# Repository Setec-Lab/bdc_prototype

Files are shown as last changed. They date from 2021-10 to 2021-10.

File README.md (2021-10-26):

Bi-directional converter based EPS prototype for small satellites
============

### Most recent version of this repository can be found in: ###

* [GitHub](https://github.com/Setec-Lab/bdc_prototype)

### What is this repository for? ###

* This repository includes testing software, embeded related software, hardware schematics and drawings and in general everything that is needed to build a copy of the system known as **Bi-directional converter based EPS prototype for small satellites**. 

### How do I get set up? ###

* **UPDATE AS IT GROWS**

### Contribution guidelines ###

* If you want to propose a review or need to modify the code for any reason first fork this [repository](https://github.com/Setec-Lab/bdc_prototype) in your system and create a new branch for your changes. Once your changes are complete and fully tested make a pull request.
* If you just want to do local changes instead you can download a zip version of the repository and do all changes locally in your system. 

### Who do I talk to? ###

* [Juan J. Rojas](mailto:juan.rojas@itcr.ac.cr)

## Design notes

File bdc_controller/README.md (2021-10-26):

BDC Prototype -- README {#mainpage}
============

### Most recent version of this repository can be found in: ###

* [Bitbucket](https://bitbucket.org/juanjorojash/bdc_prototype/src/master)

### Documentation ###

* Full documentation in HTLM version can be found in **documentation/htlm/index.htlm**

### What is this repository for? ###

* This repository was created to be used in conjuction with the integrated system known as "BDC_Prototype.V1.1". It was created to control the PIC16F1786 installed for feedback control, and serial logging.
* Hardware version: BDC_Prototype.V1.1

### How do I get set up? ###

* Connect usign serial cable. 
* **Serial terminal** Start with the following settings BR:19200 kbps, Data: 8 bit, Parity: none, Stop bits: 1, Flow control: none. 
* **LabView logger program** A program for receiving, saving and plotting the test data is included in the repository, in the directory **logger/main.vi**. The following programs are needed in order to run this program in a PC that **does not** have LabView installed:
	* [LabVIEW Run-Time Engine 2016 - (64-bit)](http://www.ni.com/download/labview-run-time-engine-2016/6067/en/) 
	* [NI-VISA Run-Time Engine 16.0](http://www.ni.com/download/ni-visa-run-time-engine-16.0/6188/en/)
The program creates the directory **c:/BDC_logger_data** to store the data.

### Contribution guidelines ###

* If you want to propose a review or need to modify the code for any reason first clone this [repository](https://bitbucket.org/juanjorojash/bdc_prototype/src/master) in your PC and create a new branch for your changes. Once your changes are complete and fully tested ask the administrator permission to push this new branch into the source.
* If you just want to do local changes instead you can download a zip version of the repository and do all changes locally in your PC. 

### Who do I talk to? ###

* [Juan J. Rojas](mailto:juan.rojas@itcr.ac.cr)

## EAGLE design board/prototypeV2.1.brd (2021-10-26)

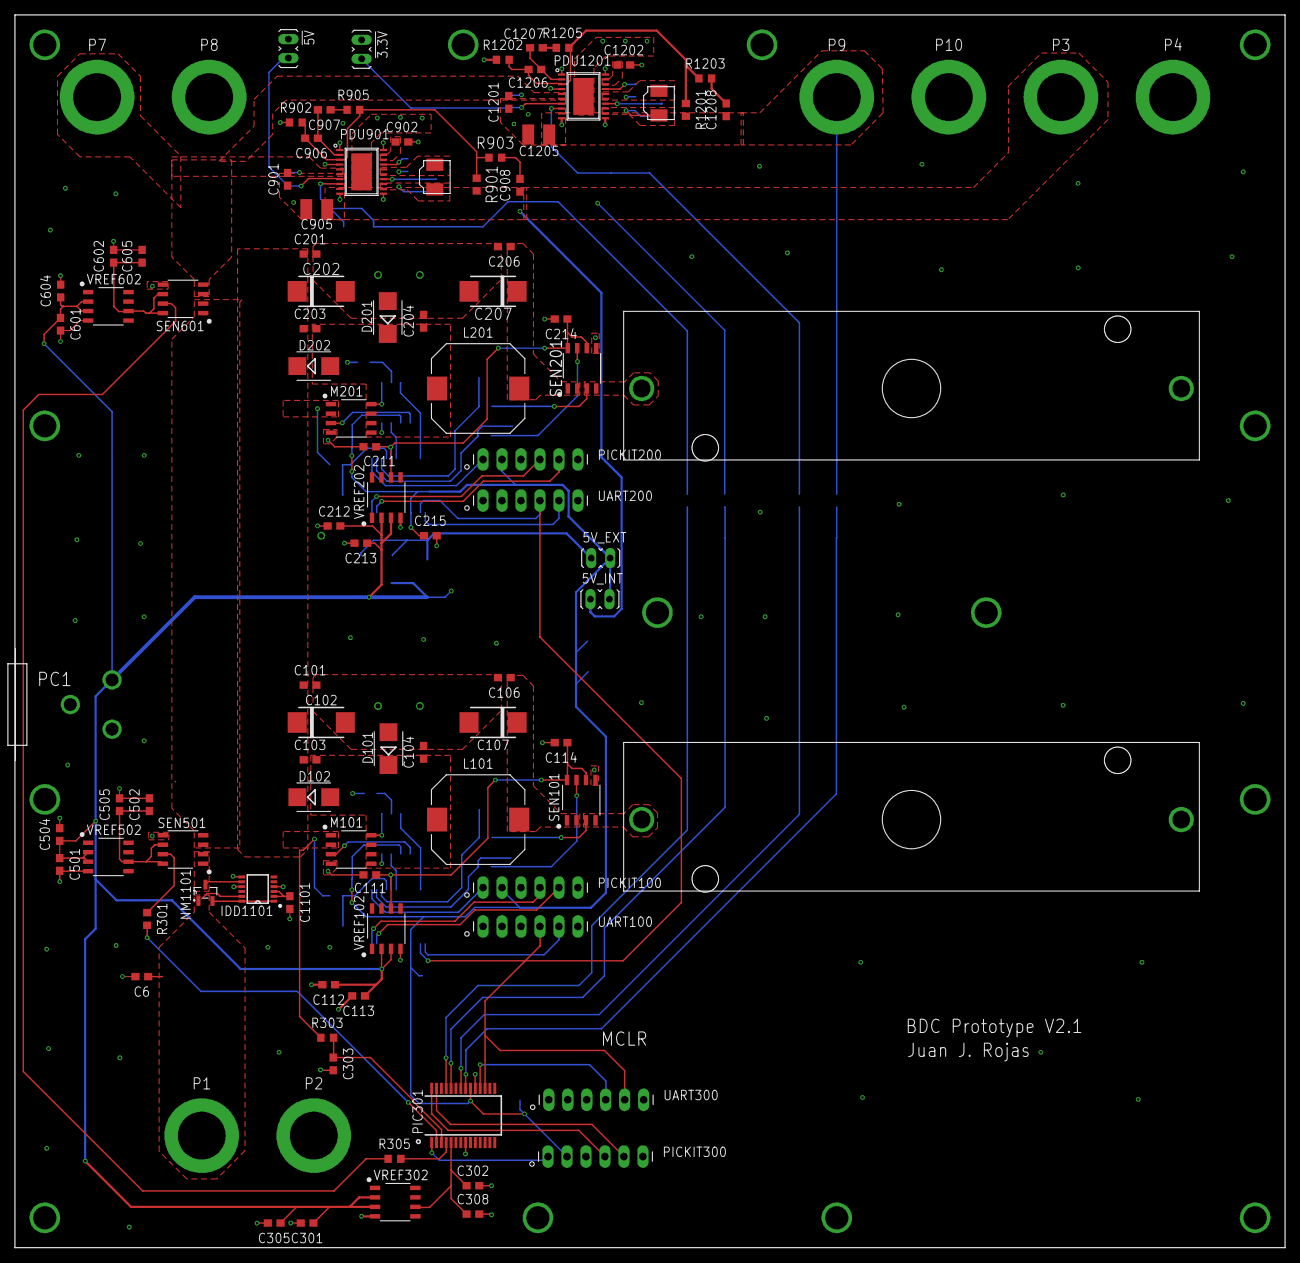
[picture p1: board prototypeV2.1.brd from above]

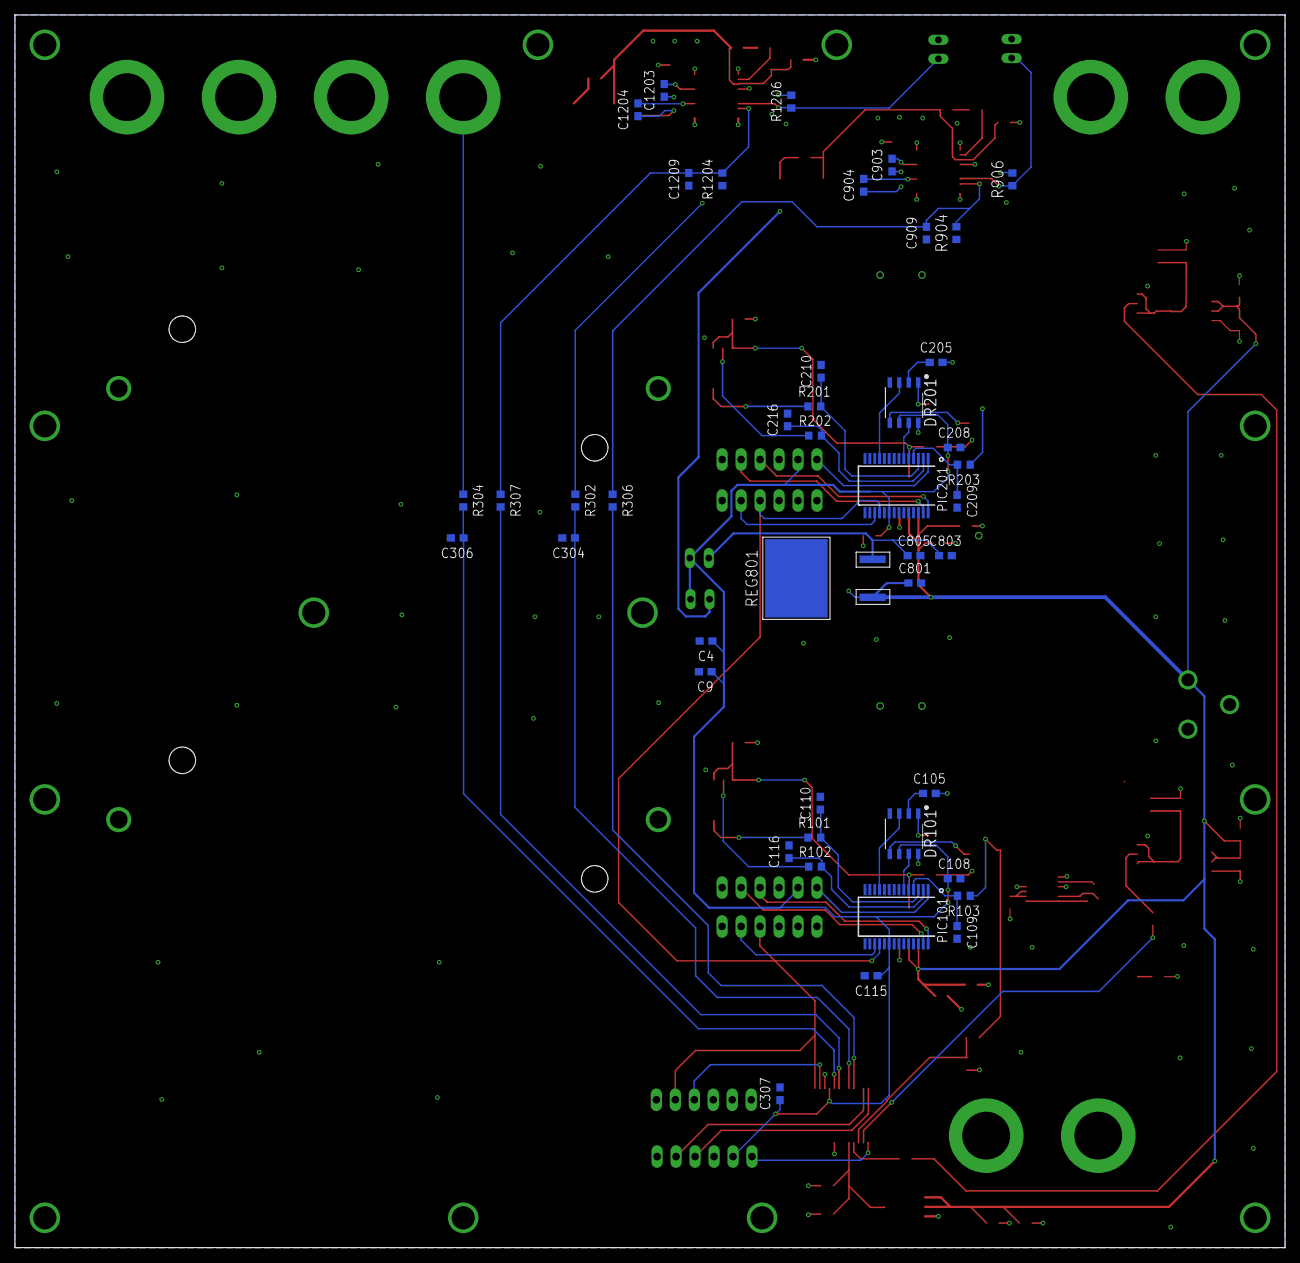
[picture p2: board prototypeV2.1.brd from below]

Board: 2 copper layers, 170.0 x 165.0 mm, 148 parts (44 on the bottom side), 85 nets.

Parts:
5V_EXT, 5V_INT: J2P
!3.3V, !5V: J2P
C4, C109, C110, C114, C115, C209, C210, C214, C215, C303, C304, C306, C307, C308, C505, C605, C903, C904, C1101, C1203, C1204: 0.1u; C0603
C6, C101, C105, C106, C111, C113, C201, C205, C206, C211, C213, C302, C305, C502, C504, C602, C604, C803, C902, C1202: 1u; C0603
C9, C112, C212, C301, C501, C601, C805, C901: 10u; C0603
C102, C107, C202, C207: 33u; C7343
C103, C104, C116, C203, C204, C216: 1n; C0603
C108, C208: 2.2u; C0603
C801: 0.33u; C0603
C905, C1205: 47u; C1210
C906: 22p; C0603
C907: 680p; C0603
C908: 47p; C0603
C909, C1209: 100p; C0603
C1201: 22u; C0603
C1206: 15p; C0603
C1207: 820p; C0603
C1208: 56p; C0603
CELL1, CELL2: CELL18650_HOLDER; 18650_HOLDER
D101, D102, D201, D202: SMB
DR101, DR201: TPS28225D; SOIC-8
IDD1101: LTC4352CMS; MSOP12
L101, L201: 22u; CLF12555
L901, L1201: 4.7u; SPM4020T
M101, M201: SI4914BDY; SOIC-8
NM1101: IRLML6244TRPBF; SOT-23
P1, P2, P3, P4, P7, P8, P9, P10: TJ-563
PC1: 722RA
PDU901, PDU1201: LTC3112EFE; TSSOP20CA
PIC101, PIC201, PIC301: PIC16F1786-I/SS; SSOP28
PICKIT100, PICKIT200, PICKIT300: MA06-1
R101, R103, R201, R203, R302, R303, R304: 200; R0603
R102, R202, R301, R305, R306, R307: 0; R0603
R901: 845k; R0603
R902: 158k; R0603
R903, R906, R1206: 10k; R0603
R904, R1204: 42.2k; R0603
R905: 33k; R0603
R1201: 620k; R0603
R1202: 200k; R0603
R1203: 9.1k; R0603
R1205: 39k; R0603
REG801: NCV7805BD2TG; D2PAK-3
SEN101, SEN201, SEN501, SEN601: ACS723-05AB-T; SOIC-8
UART100, UART200, UART300: MA06-1
VREF102, VREF202, VREF302, VREF502, VREF602: REF195GSZ; SOIC-8

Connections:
3.3V_PL: C1205.1, C1208.1, P9.P, PDU1201.9, R304.1, R1201.2
5V_ON: !5V.2, PDU901.7, R906.1
5V_PL: 5V_INT.1, C905.1, C908.1, P3.P, PDU901.9, R302.1, R901.2
7.5V: C112.1, C113.1, C212.1, C213.1, C301.1, C305.1, C501.1, C504.1, C601.1, C604.1, C801.1, PC1.PIN, REG801.1, VREF102.2, VREF102.3, VREF202.2, VREF202.3, VREF302.2, VREF302.3, VREF502.2, VREF502.3, VREF602.2, VREF602.3
12V_ON: !3.3V.2, PDU1201.7, R1206.1
+5V: 5V_EXT.2, 5V_INT.2, C4.1, C9.1, C108.1, C115.1, C208.1, C215.1, C307.1, DR101.6, DR201.6, PIC101.20, PIC201.20, PIC301.20, PICKIT100.2, PICKIT200.2, PICKIT300.2
COM_RX: PIC101.18, PIC201.18, PIC301.17, UART100.4, UART200.4, UART300.5
CONTROL:5V_REF: C302.1, C308.1, PIC301.5, VREF302.6
CONTROL:ICSPCLK: PIC301.27, PICKIT300.5
CONTROL:ICSPDAT: PIC301.28, PICKIT300.4
CONTROL:I_LOAD: PIC301.4, R305.2
CONTROL:I_PDU_3.3V: PIC301.22, R307.2
CONTROL:I_PDU_5V: PIC301.25, R306.2
CONTROL:I_PV: PIC301.2, R301.2
CONTROL:MCLR: PIC301.1, PICKIT300.1
CONTROL:RX: PIC301.18, UART300.4
CONTROL:V_BUS: C303.1, PIC301.3, R303.2
CONTROL:V_PDU_3.3V: C306.1, PIC301.21, R304.2
CONTROL:V_PDU_5V: C304.1, PIC301.24, R302.2
CONV1:5V_REF: C111.1, C114.1, PIC101.5, SEN101.6, SEN101.8, VREF102.6
CONV1:DR_EN: DR101.7, PIC101.6
CONV1:G1: DR101.1, M101.8
CONV1:G2: DR101.5, M101.3
CONV1:ICSPCLK: PIC101.27, PICKIT100.5
CONV1:ICSPDAT: PIC101.28, PICKIT100.4
CONV1:IS_BAT: C116.1, PIC101.2, R102.2
CONV1:I_BAT: R102.1, SEN101.7
CONV1:LO: C106.1, C107.+, L101.2, SEN101.1, SEN101.2
CONV1:MCLR: PIC101.1, PICKIT100.1
CONV1:N$2: C105.1, DR101.2
CONV1:PWM: DR101.3, PIC101.11
CONV1:SW: C103.2, C104.1, C105.2, D101.C, D102.A, DR101.8, L101.1, M101.5, M101.6, M101.7
CONV1:TX: PIC101.17, UART100.5
CONV1:VS_BAT: C110.1, PIC101.3, R101.2
CONV1:VS_BUS: C109.1, PIC101.4, R103.2
CONV2:5V_REF: C211.1, C214.1, PIC201.5, SEN201.6, SEN201.8, VREF202.6
CONV2:DR_EN: DR201.7, PIC201.6
CONV2:G1: DR201.1, M201.8
CONV2:G2: DR201.5, M201.3
CONV2:ICSPCLK: PIC201.27, PICKIT200.5
CONV2:ICSPDAT: PIC201.28, PICKIT200.4
CONV2:IS_BAT: C216.1, PIC201.2, R202.2
CONV2:I_BAT: R202.1, SEN201.7
CONV2:LO: C206.1, C207.+, L201.2, SEN201.1, SEN201.2
CONV2:MCLR: PIC201.1, PICKIT200.1
CONV2:N$2: C205.1, DR201.2
CONV2:PWM: DR201.3, PIC201.11
CONV2:SW: C203.2, C204.1, C205.2, D201.C, D202.A, DR201.8, L201.1, M201.5, M201.6, M201.7
CONV2:TX: PIC201.17, UART200.5
CONV2:VS_BAT: C210.1, PIC201.3, R201.2
CONV2:VS_BUS: C209.1, PIC201.4, R203.2
GND: !3.3V.1, !5V.1, C4.2, C6.2, C9.2, C101.2, C102.-, C104.2, C106.2, C107.-, C108.2, C109.2, C110.2, C111.2, C112.2, C113.2, C114.2, C115.2, C116.2, C201.2, C202.-, C204.2, C206.2, C207.-, C208.2, C209.2, C210.2, C211.2, C212.2, C213.2, C214.2, C215.2, C216.2, C301.2, C302.2, C303.2, C304.2, C305.2, C306.2, C307.2, C308.2, C501.2, C502.2, C504.2, C505.2, C601.2, C602.2, C604.2, C605.2, C801.2, C803.2, C805.2, C901.2, C902.2, C905.2, C909.1, C1101.2, C1201.2, C1202.2, C1205.2, C1209.1, CELL1.BB1.N, CELL2.BB1.N, D101.A, D201.A, DR101.4, DR201.4, IDD1101.4, IDD1101.7, IDD1101.9, M101.4, M201.4, P2.P, P4.P, P8.P, P10.P, PC1.SLEEVE, PC1.SLEEVE_SHUNT, PDU901.1, PDU901.4, PDU901.10, PDU901.11, PDU901.20, PDU901.21, PDU1201.1, PDU1201.4, PDU1201.10, PDU1201.11, PDU1201.20, PDU1201.21, PIC101.8, PIC101.19, PIC201.8, PIC201.19, PIC301.8, PIC301.19, PICKIT100.3, PICKIT200.3, PICKIT300.3, R902.1, R904.1, R1202.1, R1204.1, REG801.4, SEN101.5, SEN201.5, SEN501.5, SEN601.5, UART100.1, UART200.1, UART300.1, VREF102.4, VREF202.4, VREF302.4, VREF502.4, VREF602.4
IDEAL_D1:N$1: IDD1101.1, IDD1101.12, NM1101.2
IDEAL_D1:N$4: C1101.1, IDD1101.2, IDD1101.3
IS_LOAD: R305.1, SEN601.7
IS_PDU_3.3V: C1209.2, PDU1201.8, R307.1, R1204.2
IS_PDU_5V: C909.2, PDU901.8, R306.1, R904.2
IS_PV: R301.1, SEN501.7
LOAD_BUS: C901.1, C1201.1, P7.P, PDU901.5, PDU901.6, PDU1201.5, PDU1201.6, R906.2, R1206.2, SEN601.3, SEN601.4
unnamed: CELL1.BB1.P, R101.1, SEN101.3, SEN101.4
unnamed: CELL2.BB1.P, R201.1, SEN201.3, SEN201.4
unnamed: 5V_EXT.1, C803.1, C805.1, REG801.3
unnamed: IDD1101.8, NM1101.3, SEN501.1, SEN501.2
PDU_3.3V:N$1: C1203.2, PDU1201.17
PDU_3.3V:N$2: C1202.1, PDU1201.18, PDU1201.19
PDU_3.3V:N$3: C1204.2, PDU1201.14
PDU_3.3V:N$4: C1203.1, L1201.1, PDU1201.15, PDU1201.16
PDU_3.3V:N$5: C1207.1, R1205.1
PDU_3.3V:N$6: C1206.1, C1207.2, PDU1201.2
PDU_3.3V:N$7: C1204.1, L1201.2, PDU1201.12, PDU1201.13
PDU_3.3V:N$8: C1208.2, R1203.2
PDU_3.3V:N$9: C1206.2, PDU1201.3, R1201.1, R1202.2, R1203.1, R1205.2
PDU_5V:N$1: C903.2, PDU901.17
PDU_5V:N$2: C902.1, PDU901.18, PDU901.19
PDU_5V:N$3: C904.2, PDU901.14
PDU_5V:N$4: C903.1, L901.1, PDU901.15, PDU901.16
PDU_5V:N$5: C907.1, R905.1
PDU_5V:N$6: C906.1, C907.2, PDU901.2
PDU_5V:N$7: C904.1, L901.2, PDU901.12, PDU901.13
PDU_5V:N$8: C908.2, R903.2
PDU_5V:N$9: C906.2, PDU901.3, R901.1, R902.2, R903.1, R905.2
PV: C6.1, IDD1101.11, NM1101.1, P1.P
PV_BUS: C101.1, C102.+, C103.1, C201.1, C202.+, C203.1, D102.C, D202.C, M101.1, M101.2, M201.1, M201.2, R103.1, R203.1, R303.1, SEN501.3, SEN501.4, SEN601.1, SEN601.2
SENS_LOAD:5V_REF: C602.1, C605.1, SEN601.6, SEN601.8, VREF602.6
SENS_PV:5V_REF: C502.1, C505.1, SEN501.6, SEN501.8, VREF502.6

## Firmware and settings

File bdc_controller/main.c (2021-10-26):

/**
 * @file main.c
 * @author Juan J. Rojas
 * @date 10 Nov 2018
 * @brief main loop for the BDC prototype controller or converter.
 * @par Institution:
 * LaSEINE / CeNT. Kyushu Institute of Technology.
 * @par Mail (after leaving Kyutech):
 * juan.rojas@tec.ac.cr
 * @par Git repository:
 * https://bitbucket.org/juanjorojash/bdc_prototype/src/master
 */

#include "hardware.h"

/**@brief This is the main function of the program.
*/


void main(void)
{
    initialize(); /// * Call the #initialize() function
    __delay_ms(10);
    interrupt_enable();
    voc = sVOC; 
    ivbusr = sVREF;
    vbusr = sVREF;
    vbatmin = sVBATMIN;
    vbatmax = sVBATMAX;
    iref = sCREF;
    log_on = 1;
    while(1)
    {           
        if (SECF) /// * The following tasks are executed every second:
        {     
            SECF = 0;
            log_control_hex();
        }       
	}
}

/**@brief This is the interruption service function. It will stop the process if an @b ESC or a @b "n" is pressed. 
*/
void __interrupt() ISR(void) 
{
    char recep = 0; /// Define and initialize @p recep variable to store the received character
    
    if(TMR1IF)
    {
        TMR1H = 0xE1; //TMR1 Fosc/4= 8Mhz (Tosc= 0.125us)
        TMR1L = 0x83; //TMR1 counts: 7805 x 0.125us x 8 = 7805us
        TMR1IF = 0; //Clear timer1 interrupt flag
        vpv = read_ADC(V_BUS);
        ipv = read_ADC(I_PV);
        ipv = (uint16_t) abs(ipv - 2048); 
        if ( mppt )
        {
//            if ( ipv > 20 )
//            {
//                PAO(vpv, ipv, &power, &dir);
//            }
//            else DIRECTION(0x08);
            
            CV(vpv, sVREF, &dir);
            DIRECTION(dir);
        }
        ilo = read_ADC(I_LOAD);
        ilo = (uint16_t) abs(ilo - 2048);
        v50 = read_ADC(V_PDU_50V);
        i50 = read_ADC(I_PDU_50V);
        v33 = read_ADC(V_PDU_33V);
        i33 = read_ADC(I_PDU_33V);
        calculate_avg(); /// * Then, averages for the 250 values available each second are calculated by calling the #calculate_avg() function
        timing(); /// * Timing control is executed by calling the #timing() function         
    }
    
    if(RCIF)/// If the UART reception flag is set then:
    {
        if(RC1STAbits.OERR) /// * Check for errors and clear them
        {
            RC1STAbits.CREN = 0;  
            RC1STAbits.CREN = 1; 
        }
        while(RCIF) recep = RC1REG; /// * Empty the reception buffer and assign its contents to the variable @p recep
        switch (recep)
        {
        case 0x63: /// * If @p recep received a @b "c", then:
            STOP;
            mppt=0;
            break;
        case 0x73: /// * If @p recep received an @b "s", then:
            RESET_TIME();
            START;
            mppt=1;
            break;
        case 0x69: /// * If @p recep received an @b "i", then:
            DIRECTION(0x06);
            break;
        case 0x64: /// * If @p recep received an @b "d", then:
            DIRECTION(0x07);
            break;
        case 0x72: /// * If @p recep received an @b "r", then:
            DIRECTION(0x09);
            break;
        default:
            recep = 0;
        }
    }  
   
}

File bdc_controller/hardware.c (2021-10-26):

/**
 * @file harware.c
 * @author Juan J. Rojas
 * @date 10 Nov 2018
 * @brief function definitions for the BDC prototype controller.
 * @par Institution:
 * LaSEINE / CeNT. Kyushu Institute of Technology.
 * @par Mail (after leaving Kyutech):
 * juan.rojas@tec.ac.cr
 * @par Git repository:
 * https://bitbucket.org/juanjorojash/bdc_prototype/src/master
 */

#include "hardware.h"

/**@brief Function to define initialize the system
*/
void initialize()
{
    /** @b GENERAL*/
    CLRWDT(); /// * Clear WDT by calling @p CLRWDT()
    nWPUEN = 0; /// * Allow change of individual WPU
    WPUE3 = 1;      //Enable pull up for MCLR
    /** @b SYSTEM @b CLOCK*/
    /** PLL is always enabled because of configuration bits*/
    OSCCONbits.IRCF = 0b1111; /// * Set clock to 32MHz (with PLL)
    OSCCONbits.SCS = 0b00; /// * Clock determined by FOSC<2:0> in Configuration Words
    OSCCONbits.SPLLEN = 1; /// * Enable PLL. According to Errata this shall not be done in the Configuration Words
    /** @b TIMER 1 for control and measuring loop using interruption*/
    /* Preload TMR1 register pair for 1us overflow*/
    /* T1OSCEN = 1, nT1SYNC = 1, TMR1CS = 0 and TMR1ON = 1*/
    nT1SYNC = 0;     //Synchronized
    T1OSCEN = 0;
    TMR1ON = 0;       //ON
    TMR1GE = 0;      //Dont care about gate
    TMR1CS0 = 0;       
    TMR1CS1 = 0;    //FOSC/4
    T1CKPS0 = 1;
    T1CKPS1 = 1;    // 8 milliseconds
    TMR1H = 0xE1;   //TMR1 Fosc/4= 8Mhz (Tosc= 0.125us)
    TMR1L = 0x83;   //TMR1 counts: 7805 x 0.125us = 0.97562ms
    /** @b ADC*/
    /** ADC INPUTS*///check this after final design
    TRISA0 = 1; /// * RA0
    ANSA0 = 1; /// * RA0 analog
    WPUA0 = 0; /// * RA0 weak pull up deactivated
    TRISA1 = 1; /// * RA1
    ANSA1 = 1; /// * RA1 analog
    WPUA1 = 0; /// * RA1 weak pull up deactivated
    TRISA2 = 1; /// * RA2
    ANSA2 = 1; /// * RA2 analog
    WPUA2 = 0; /// * RA2 weak pull up deactivated
    TRISB0 = 1; /// * RB0
    ANSB0 = 1; /// * RB0 analog
    WPUB0 = 0; /// * RB0 weak pull up deactivated
    TRISB1 = 1; /// * RB1
    ANSB1 = 1; /// * RB1 analog
    WPUB1 = 0; /// * RB1 weak pull up deactivated
    TRISB3 = 1; /// * RB3
    ANSB3 = 1; /// * RB3 analog
    WPUB3 = 0; /// * RB3 weak pull up deactivated
    TRISB4 = 1; /// * RB4
    ANSB4 = 1; /// * RB4 analog
    WPUB4 = 0; /// * RB4 weak pull up deactivated
    /** Configs*/
    ADCON0bits.ADRMD = 0; /// * 12 bits result
    ADCON1bits.ADCS = 0b010; /// * Clock selected as FOSC/32
    ADCON1bits.ADNREF = 0; /// * Connected to Vss
    ADCON1bits.ADPREF = 0b01; /// * Connected to Vref+
    //ADCON1bits.ADPREF = 0b00; /// * Connected to VDD
    ADCON1bits.ADFM = 1; /// * 2's compliment result
    ADCON2bits.CHSN = 0b1111; /// * Negative differential input as ADNREF
    ADCON0bits.ADON = 1; /// * Turn on the ADC
    /** @b UART*/
    //**Setting I/O pins for UART*/
    TXSEL = 0;      /// * RC6 selected as TX
    RXSEL = 0;      /// * RC7 selected as RX
    //________I/O pins set __________//
    
    /**Initialize SPBRG register for required 
    baud rate and set BRGH for fast baud_rate**/
    SP1BRGH = 0x00;  //Set to 57.6 kbps
    SP1BRGL = 0x8A;    
    BRGH  = 1;  /// * for high baud_rate
    BRG16 = 1;  /// * for 16 bits timer
    //_________End of baud_rate setting_________//
    
    //****Enable Asynchronous serial port*******//
    SYNC  = 0;    /// * Asynchronous
    SPEN  = 1;    /// * Enable serial port pins
    //_____Asynchronous serial port enabled_______//
    //**Lets prepare for transmission & reception**//
    TXEN  = 1;    /// * enable transmission
    CREN  = 1;    /// * enable reception
    //__UART module up and ready for transmission and reception__//
    //**Select 8-bit mode**//  
    TX9   = 0;    /// * 8-bit reception selected
    RX9   = 0;    /// * 8-bit reception mode selected
    //__8-bit mode selected__/
    RCIE = 0; /// * Disable UART reception interrupts
    TXIE = 0; /// * Disable UART transmission interrupts
}
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

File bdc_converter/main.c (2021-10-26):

/**
 * @file main.c
 * @author Juan J. Rojas
 * @date 10 Nov 2018
 * @brief main loop for the BDC prototype converter.
 * @par Institution:
 * LaSEINE / CeNT. Kyushu Institute of Technology.
 * @par Mail (after leaving Kyutech):
 * juan.rojas@tec.ac.cr
 * @par Git repository:
 * https://bitbucket.org/juanjorojash/bdc_prototype/src/master
 */

#include "hardware.h"

/**@brief This is the main function of the program.
*/
void main(void)
{
    initialize(); /// * Call the #initialize() function
    __delay_ms(10);
    interrupt_enable();
    log_on = 1;
    while(1)
    {   
        if (recep_flag)
        {
            recep_flag = 0;
            switch (recep[0])
            {
                case 0x01: ///
                    if (char_count == 3) char_count++;
                    else char_count = 0;
                    break;
                case 0x03:
                    if (recep[1] == 0x01 || char_count == 2) char_count++;
                    else char_count = 0;
                    break;
                case 0x04:
                case 0x05: 
                case 0x06:
                case 0x07:
                case 0x08:
                    if (char_count == 1)
                    {
                        action = recep[0];
                        char_count++;
                    }else char_count = 0;
                    break;
                default: 
                    char_count = 0;
                }
                if (char_count == 4)
                {
                    switch (action)
                    {
                        case 0x04:
                            START_CONVERTER(); /// -# Start the converter by calling the #START_CONVERTER() macro.
                            RESET_TIME();
                            break;
                        case 0x05:
                            STOP_CONVERTER(); /// -# Stop the converter by calling the #STOP_CONVERTER() macro.
                            RESET_TIME();
                            break;
                        case 0x06:
                            dc++;
                            if (dc > DC_MAX) dc = DC_MAX;
                            break;
                        case 0x07:
                            dc--;
                            if (dc < DC_MIN) dc = DC_MIN;
                            break;
                        case 0x08:
                            break;
                    }
                    action = 0;
                    char_count = 0;
                }
        } 
        
        if (SECF)
        {
            SECF = 0;
            log_control_hex();
            //if ((vbatav < vbatmax) && (vbusr > ivbusr)) vbusr -= 2;
            if (vbatav < vbatmin)STOP_CONVERTER();
        }
	}
}

/**@brief This is the interruption service function. It will stop the process if an @b ESC or a @b "n" is pressed. 
*/
void __interrupt() ISR(void) 
{
    //char recep = 0; /// Define and initialize @p recep variable to store the received character
    
    if(TMR1IF)
    {
        TMR1H = 0xE1; //TMR1 Fosc/4= 8Mhz (Tosc= 0.125us)
        TMR1L = 0x83; //TMR1 counts: 7805 x 0.125us = 975.625us
        TMR1IF = 0; //Clear timer1 interrupt flag
        vbus = read_ADC(VS_BUS); /// * Then, the ADC channels are read by calling the #read_ADC() function
        vbat = read_ADC(VS_BAT); /// * Then, the ADC channels are read by calling the #read_ADC() function
        ibat = (int16_t)(read_ADC(IS_BAT)); /// * Then, the ADC channels are read by calling the #read_ADC() function
        //HERE 2154 is a hack to get 0 current
        ibat = 2048 - ibat; 
        if (conv){
//            control_loop(); /// -# The #control_loop() function is called*/
//            //if ((vbat >= vbatmax) && (vbusr < voc)) vbusr +=1; ///NEEDS CORRECTION
            set_DC(&dc);
        }
        calculate_avg(); /// * Then, averages for the 250 values available each second are calculated by calling the #calculate_avg() function
        timing(); /// * Timing control is executed by calling the #timing() function         
    }
    
    if(RCIF)/// If the UART reception flag is set then:
    {
        if(RC1STAbits.OERR) /// * Check for errors and clear them
        {
            RC1STAbits.CREN = 0;  
            RC1STAbits.CREN = 1; 
        }
        recep[1] = recep[0];
        recep[0] = RC1REG; /// * Empty the reception buffer and assign its contents to the variable @p recep   
        recep_flag = 1;
    }  
}
